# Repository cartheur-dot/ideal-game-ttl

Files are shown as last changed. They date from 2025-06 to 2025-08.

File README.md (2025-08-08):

## ideal-game-ttl

Playing around is more than half of the fun.

### References

* RAM[7400](https://github.com/emotional-toys/RAM7400)
* aeon-[ttl](https://github.com/emotional-toys/aeon-ttl)
* [SRAM](https://www.jameco.com/c/SRAM-Memory.html)

# Adding a Guess Counter to the "Guess the Hidden Number" Game

To enhance the "Guess the Hidden Number" game with a **guess counter** that tracks the number of guesses (LOAD button presses) a player makes, we’ll add logic to the existing circuit (2114 RAM, 8226, LM555, 74LS73, 74LS00, 74LS244, 74LS85, SPST switches, LEDs). The counter displays the number of guesses on LEDs and resets upon a correct guess or manual reset. The goal is to minimize additional ICs while reinforcing the reinforcement learning (RL) analogy.

## Counter Design Overview
- **Purpose**: Count LOAD button presses (guesses), display the count, and reset when the player wins (correct guess) or starts a new game.
- **Display**: Use a 4-bit binary counter (0–15 guesses) with 4 LEDs to keep the design simple, avoiding complex 7-segment display drivers.
- **Logic**:
  - Increment the counter each time the LOAD button is pressed (using the same pulse as RAM read and 74LS85 comparison).
  - Reset when the 74LS85 indicates a correct guess (`O_A=B` = 1) or via an optional manual reset switch.
- **Components**:
  - **74LS93** (4-bit binary counter) for counting.
  - 4 LEDs for binary display.
  - Reuse existing 74LS73 and 74LS00 for control signals.

## Circuit Modifications
The counter integrates with the existing circuit by using the LOAD pulse (from 74LS73) to increment and the 74LS85’s `O_A=B` output to reset. Here’s the implementation:

### 1. Counter IC: 74LS93 (4-bit Binary Counter)
- **Description**: The 74LS93 is a 4-bit ripple counter with a divide-by-2 (QA) and divide-by-8 (QB–QD) section, counting from 0000 to 1111 (0–15), sufficient for tracking guesses (typically ≤4 with binary search).
- **Pinout** (14-pin DIP):
  - **CKA (pin 14)**: Clock for QA (increments on falling edge).
  - **CKB (pin 1)**: Clock for QB–QD (connect to QA for 4-bit counting).
  - **R0(1), R0(2) (pins 2, 3)**: Reset inputs (active high, both high to reset).
  - **QA–QD (pins 12, 9, 8, 11)**: Outputs (QA = LSB, QD = MSB).
  - **VCC (pin 5)**: 5V.
  - **GND (pin 10)**: Ground.
- **Connections**:
  - **Clock**: Connect CKA (pin 14) to 74LS73 Q output (pin 5, `LOAD` pulse for `CS` and `WE`). Q’s falling edge (after `LOAD` release) triggers the counter.
  - **CKB**: Connect to QA (pin 12) for 4-bit counting.
  - **Reset**:
    - Connect R0(1) and R0(2) (pins 2, 3) to 74LS85 `O_A=B` (pin 5) via a 74LS00 NAND gate for reset on correct guess.
    - Example: Use a 74LS00 NAND gate (pins 1, 2 input, pin 3 output) with `O_A=B` and delayed LOAD pulse (via RC or second 74LS73 flip-flop) as inputs.
  - **Outputs**: Connect QA–QD (pins 12, 9, 8, 11) to 4 LEDs (L12–L15) via 550Ω bussed resistor network (1kΩ):
    - L12: QA (bit 0, LSB).
    - L13: QB (bit 1).
    - L14: QC (bit 2).
    - L15: QD (bit 3, MSB).
    - LED cathodes to GND.
  - **Decoupling**: Add 0.1 µF capacitor near pin 5 (VCC).

  _Connections_
  ```
  74LS93 (14-pin DIP)
  Pin 14 (CKA) --- 74LS73 Q (pin 5, LOAD pulse)
  Pin 1  (CKB) --- Pin 12 (QA)
  Pin 12 (QA) ---[330Ω]--- L12 (LED) --- GND
  Pin 9  (QB) ---[330Ω]--- L13 (LED) --- GND
  Pin 8  (QC) ---[330Ω]--- L14 (LED) --- GND
  Pin 11 (QD) ---[330Ω]--- L15 (LED) --- GND
  Pin 2  (R0(1)) --- 74LS00 NAND output (`O_A=B` & `LOAD`) or S15 (`VCC` w/ 10kΩ pull-down)
  Pin 3  (R0(2)) --- Same as R0(1)
  Pin 5  (VCC) --- 5V + [0.1µF capacitor] --- GND
  Pin 10 (GND) --- GND
  Pins 4, 6, 7, 13 (NC) --- Unconnected
  ```

### 2. Reset Logic
- **Automatic Reset**:
  - Reset 74LS93 when 74LS85 `O_A=B` = 1 (correct guess).
  - Use a 74LS00 NAND gate to combine `O_A=B` with LOAD pulse (74LS73 Q):
    - Inputs: `O_A=B` (74LS85 pin 5), Q (74LS73 pin 5).
    - Output: To R0(1) and R0(2) (74LS93 pins 2, 3).
    - Resets counter only on correct guess with LOAD.
- **Manual Reset** :
  - Add SPST push-button (S15) for manual reset (new game without correct guess).
  - Connect S15 between VCC and R0(1)/R0(2) with 10 kΩ pull-down resistors to GND.
  - When pressed, S15 sets R0(1) = R0(2) = 1, resetting to `0000`.

### 3. Control Integration
- **LOAD Pulse**: 74LS73 Q (pin 5) triggers:
  - 2114 RAM read (\(\overline{\text{CS}} = 0\), \(\overline{\text{WE}} = 1\)).
  - 74LS85 comparison.
  - 74LS93 increment (via CKA).
- **Timing**:
  - 1 kHz clock (LM555) ensures synchronized LOAD pulse, preventing multiple counts from button bounce.
  - 74LS93’s ~20 ns ripple delay is negligible for 1 ms clock period.
- **74LS00 Usage**:
  - Uses two NAND gates for \(\overline{\text{CS}}\) and \(\overline{\text{WE}}\) (original circuit).
  - Third gate for counter reset (`O_A=B` and `LOAD`).
  - Fourth gate for manual reset (S15).

### 4. Display
- **4 LEDs (L12–L15)**: Show guess count in binary (e.g., `0011` = 3 guesses).
- **Interpretation**: Players read binary (assume familiarity, common in digital logic contexts). Provide a reference chart (e.g., 0001 = 1, 0010 = 2).
- **Optional 7-Segment Display**:
  - A 74LS47 BCD-to-7-segment decoder and display add 1 IC and complexity. Binary LEDs minimize components.

### 5. 75LS85 Connections

```
74LS85 (16-pin DIP)
  Pin 5 (O_A>B) ---[330Ω]--- L9 (Red LED) --- GND
  Pin 7 (O_A<B) ---[330Ω]--- L10 (Yellow LED) --- GND
  Pin 6 (O_A=B) ---[330Ω]--- L11 (Green LED) --- GND
  Pin 2 (A0) ---- S9 (D0 switch)
  Pin 3 (A1) ---- S10 (D1 switch)
  Pin 4 (A2) ---- S11 (D2 switch)
  Pin 5 (A3) ---- S12 (D3 switch)
  Pin 15 (B0) --- 2114 I/O1 (pin 11)
  Pin 14 (B1) --- 2114 I/O2 (pin 12)
  Pin 13 (B2) --- 2114 I/O3 (pin 13)
  Pin 12 (B3) --- 2114 I/O4 (pin 14)
  Pin 10 (I_A>B) --- GND
  Pin 11 (I_A<B) --- GND
  Pin 9  (I_A=B) --- VCC
  Pin 16 (VCC) --- 5V + [0.1µF capacitor] --- GND
  Pin 8  (GND) --- GND
  ```

## Updated Gameplay
The game remains "Guess the Hidden Number," with the counter tracking guesses to enhance the RL analogy (minimize guesses = maximize reward).

1. **Setup**:
   - Store a 4-bit number in 2114 RAM at address `000000`, `PROGRAM`, lamps indicate data switch values; S13 = 0, `LOAD`.
   - Set address switches (S1–S6) to `000000`, R/P switch (S13) to `READ` (1), lamps indicate state from RAM.
   - Reset counter via S15 or power-on, 74LS93 outputs `0000`.

2. **Gameplay**:
   - **Step 1: Input Guess**:
     - Set data switches (S9–S12) to a 4-bit guess (e.g., `1000` = `8`).
     - Input LEDs (L1–L4) show the guess.
   - **Step 2: Submit Guess**:
     - Press LOAD (S14). 74LS73 pulse triggers:
       - 2114 RAM read (outputs stored number to 74LS85).
       - 74LS85 comparison (guess vs. stored number).
       - 74LS93 increment (e.g., `0000` → `0001`).
     - Feedback LEDs (L9–L11):
       - Red (L9): Too high `O_A>B`.
       - Yellow (L10): Too low `O_A<B`.
       - Green (L11): Correct `O_A=B`.
     - Counter LEDs (L12–L15) show count (e.g., `0001` = 1 guess).
   - **Step 3: Adjust Guess**:
     - Adjust switches based on feedback (e.g., if 8 is too low, try `1100` = `12`).
   - **Step 4: Repeat**:
     - Repeat until green LED (L11) lights.
     - On correct guess, `O_A=B` = 1 resets 74LS93 to `0000`.

3. **Winning**:
   - Win when green LED (L11) lights.
   - Note final guess count on L12–L15 before reset (e.g., `0011` = 3 guesses).
   - Optionally, enable 74LS244 to show stored number on L5–L8.

4. **New Game**:
   - Store new number or reuse same.
   - Reset counter via S15 or power cycle.

5. **RL Enhancement**:
   - **Reward**: Minimize guess count (L12–L15). Each guess = negative reward; winning = high cumulative reward.
   - **Learning**: Players refine strategy (e.g., binary search) to reduce guesses, mimicking RL policy optimization.
   - Example: Binary search takes ≤4 guesses for 0–15.

## Example Gameplay with Counter
- **Hidden Number**: 1010 (10).
- **Guess 1**: Set S9–S12 to 1000 (8), press LOAD.
  - 74LS85: 8 < 10 → Yellow LED (L10).
  - 74LS93: 0000 → 0001 (L12 on, 1 guess).
- **Guess 2**: Set 1100 (12), press LOAD.
  - 74LS85: 12 > 10 → Red LED (L9).
  - 74LS93: 0001 → 0010 (L13 on, 2 guesses).
- **Guess 3**: Set 1010 (10), press LOAD.
  - 74LS85: 10 = 10 → Green LED (L11).
  - 74LS93: 0010 → 0011 (L12, L13 on, 3 guesses), then resets to 0000.
- **Result**: Win in 3 guesses, counter shows 0011 briefly, then resets.

## Updated Bill of Materials (BoM)
| Component | Quantity | Description |
|---|---|---|
| **2114** | 1 | 1024 x 4-bit static RAM IC |
| **i8226** | 1 | 4-bit bus driver for data bus (16-pin DIP) |
| **LM555** | 1 | 555 Timer IC for 1 kHz clock |
| **74LS73** | 1 | Dual JK flip-flop for debouncing |
| **74LS00** | 1 | Quad 2-input NAND gate for control logic |
| **74LS00** | 8 | Quad 2-input NAND gate for control logic (RAM7400) |
| **74LS244** | 1 | Octal buffer/line driver for output LEDs |
| **74LS85** | 1 | 4-bit magnitude comparator for game logic |
| **74LS93** | 1 | 4-bit binary counter for guess tracking |
| **SPST Switch**  | 11 | 6 for address (S1–S6), 4 for data (S9–S12), 1 for read/write (S13) |
| **SPST Push-Button** | 2 | LOAD button (S14), Reset button (S15) |
| **LED** | 15 | 6 for address (S1–S6), 4 for input/output (L1-L4/L5–L8), 3 for feedback (L9: red, L10: yellow, L11: green), 4 for counter (L12–L15) |
| **Resistor** | 32 | 14 pull-up (4.7 kΩ), 14 pull-down (22 kΩ) for switches; 5 current-limiting resistor networks (550 Ω) for LEDs |
| **Capacitor** | 7 | 1 for 555 timer (0.1 µF), 6 for decoupling (0.1 µF near each IC) |
| **Power Supply** | 1 | 5V DC regulated supply |

**Total ICs (#pins)**: 2114 (18), LM555 (8), 74LS73 (14), 74LS00 (14), 74LS244 (20), 74LS85 (16), 74LS93(14); 7404 (14), 74LS367 (16), 8226 (16); 500-ohm-sip (14), 1k-ohm sip (18), 0.1uF (8).

## Notes
- **IC Count**: 74LS93 adds 1 IC, the simplest 4-bit counter. Cascading flip-flops (e.g., 74LS73) would require more ICs.
- **Display Simplicity**: Binary LEDs (L12–L15) minimize components vs. a 7-segment display (74LS47 + display = +1 IC, +7 resistors).
- **Reset Options**: Automatic reset (O_A=B) suffices; S15 (manual reset) is optional for testing/restarting.
- **RL Fidelity**: Counter quantifies performance (guess count = negative reward), encouraging players to optimize strategy (e.g., binary search).
- **Scalability**: For >15 guesses, cascade two 74LS93s (8-bit), but unnecessary for typical 2–4 guess range.
- **Timing**: 74LS93’s ~20 ns ripple delay is negligible for 1 kHz clock (1 ms) and human interaction.

## Conclusion
The 74LS93 counter, with 4 LEDs and minimal logic, tracks guesses, enhancing the RL analogy by quantifying performance. It integrates seamlessly, using the LOAD pulse to increment and O_A=B to reset. Players minimize guesses, mirroring RL policy optimization.

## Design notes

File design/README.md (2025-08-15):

## The design of breadboard

* Top: Two 4-bit switchers (address), one led-indicator-switches (data-input)
* Bottom: One led-indicator-2pb-switch (data-output|LOAD|RESET|R/P), one led-indicator-three (CORRECT|HIGH|LOW), one led-indicator-four (counter guess tracking)

_Print_

* 4-bit-switcher (2)
* switches-indicator-four (1) Swapped version of the original
* led-indicator-2pb-switch (1) 
* led-indicator-four (1)
* led-indicator-three (1)

### Nibble-RAM feature

[this](https://www.instructables.com/DIY-RAM-for-Your-Micro/)

### Communication

From the state of power-off to power-on, 2114 should be empty, but it is not.

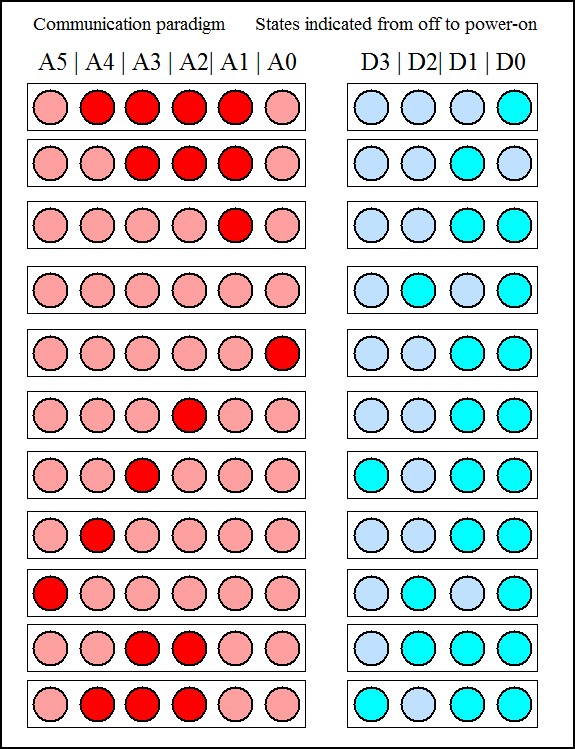
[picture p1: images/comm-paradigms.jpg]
paradigm


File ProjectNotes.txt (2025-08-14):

June 2025
Ideal game ttl

13.06.2025
    2234: Feeling gamed by the distraction of henry at the expense of dot-aeon-ttl, will shed the fiction of dotnet and return to what is real. But since unsure where to go, will start with this "Guess the number" game with the parts I have imagined. Just now finished the set of prints for the user-interface and will mount on another card, not altering what I have already created for dot.
15.06.2025
    1121: Pushing to prepare the models for printing. Will think on a "set of shared features" for ente evolving array of logic boards.
    1135: Trying an experiment to print the feature-set that belongs to the project, rather than each individually. Also generate collective stl file.
    1443: Two failed prints due to breaking-away. Maybe the 30% fill. Will print the two chunkers at default 15%.
    1722: Funk-dat, 4-bit switcher is wrongly-sized. Another print needed. Can still drill but not glue-set.
    1731: Created a two-set print of correct model.
17.06.2025
    1218: Created a project, starting-in on the UI. Need to figure a way to indicate the postion with only two LEDs.
    1230: Starting with the UI and already seeing the lameness of the AI.
    1313: Working-through the Address and Data switch-lamp, seeing buses are on the menu today.
    1413: Appended the figures to remove the second-set of components since this model is 6-bit addressing and 4-bit data.
    1418: Doping colours to ease the strain. 30,220,228 matches well.
    1533: At the 2114 diagram, still a question about the busses but need them, yes?
    1656: Generated Task03 and this is the end of this phase.
18.06.2025
    1044: Discussed RAM7400 as a way to get into memories; before that, Heiserman principle of the UI first.
    1344: Drifting toward soldering.
    1938: Soldered connections completed. COMM and 5V rails in-place. Leveraged the Vector pins with a bit of round-filing; sets well but dropped a spot of Uhoo to ensure seating over the term of the board's use.
19.06.2025
    816: Pins are set and ready to continue with the next steps.
    1148: Some minor corrections to the task diagrams and gathering the sockets. Since here, will also gather for RAM7400 since this area can be used for self-programming.
    1312: Sorted RAM7400 but needed an 8-bit port setup for the Arduino tester, which is a great interface to add larger code scenarios.
    1518: Full set of details completed for RAM7400. Ready to prototype the self-programming memory area.
    1526: Small adjustments made for clarity in documentation.
    1532: Setting-up the arduino interface.
    1640: User-interface and Arduino board ready for test on Windoze.
    1641: Sockets collected for the ideal-ttl implementation.
20.06.2025
    828: A day to continue with sockets and chips for RAM7400 dry-run.
    1038: Would be wise while at the socketing phase to understand the 2114 circuit that, as far as I know, is still not designed.
    1106: Sockets gathered. Need to add LEDs - short one but could cut a free socket for an unneeded switch.
21.06.2025
    1151: Happy Solstice! Reviewing TTL and ideal pullup values and have computed power ideal with a 4.7k resistor, using the DIP or inline types and not the silly single resistors in the Heiserman way - although in isolated form in a 16-pin DIP, this is approximately the same!
    1259: Gathered the part for the ideal aspect and listed the UI parts. Would like to begin assembly with the RAM7400 as soon as I can find a 2024 order of 2.2k bussed Bornes block resistors. Later.
    1618: Still have not found the bussers; settled on working on the UI and sized the third lamp for the success indication in the 74LS85 game.
    1811: Bussed located and set the full socket requirements for the system.
    1932: With a common ground the resistor network (bussed) is used; with a common positive the Heiserman method or isolated network is used. I suspect the following: 1. Bussed can be used on 74ls93 counter indicator, 2. Isolated on switch-LED indicator combo, 3. Bussed on pullups.
    1957: Pull parts then done for the day.
    2032: Cleaned-up the text in preparation of the build.
22.06.2025
    959: Cleared an area for digital analysis but decided against a heavy solution at the moment. Next step is to build the UI. Then, I think, the RAM7400 board to get the sense of how the logic appears.
    1003: Regarding the UI: Looking at the diagram and reading about the idea of pullup resistors, PR207 and PR208 are performing this task.
    1009: Will remove the sockets and only keep ones for the UI: 7404, 74367, 8226.
    1015: Looking at the resistor blocks (10) first as one end is connected to the 5V supply.
    1048: UI diodes: Red --> 604R; Blue --> 2.43k.
    1200: Parts are lain-out. Using the deep-cushion to mount the resistors into the 24-pin WW: SwitchRs to the left; LedRs to the right. Addresses first. Data second.
    1258: Resistors mounted, including the three RL lamps for the 7485. LEDs chosen.
    1306: Looking at the connections as the LEDs for the 7485 and the 7493 have their anodes to the respective output pins, cathode on ground.
    1401: For completeness, documented the circuit and its BoM, sans Heiserman parts.
    1403: Feeling a bit frazzled so shifting away.
    1437: Fully shifted.
23.06.2025
    2014: Still shifted. I notice that if I work through the weekend, Mondays are free.
    2021: I have contemplated the 7485 and can square the output behaviour. The only gap is from the 8226 to 2114.
    2057: Just closed the gap and updated the document.
    2110: Added the datasheet for this part.
24.06.2025
    1003: On the EVB today.
    1005: This should be a companion to aeon-ttl, as this is the prequel, the bear the product target, compact fraemwork the development environment and the output concentrated on animals-dot.
    1159: Note that this work is across three repos: This one, aeon-ttl, and animals-dot.
    1200: Finished the correction to EVB so have some free time after lunch to work on this.
    1410: Not so much free time.
    1429: 5V line to all the switch resistors, starting.
    1505: Finished the task.
    1607: Stepping into the EVB meeting.
    1846: Stepping out of the EVB meeting. Level shifters too smart for their own good.
25.06.2025
    1235: Snapping/soldering pins and WW the equivalent of U13.
    1310: Job is finished.
    1325: Thinking of the order for ideal-ttl, since the iron is here: AS0/DS0 is the extreme right (LSB).
        * Interwires between 7404 and 74367, (yellow)
        * Addr - 5V (red) and COMM (black) - internal only
        * AS resistor block to 74367, (AS0 to the inside)
        * AL resistor block to 7404, (AL0 to the inside)
        * AL to resistor block, (solder-task)
        * AS to 7404, (solder-task)
        * Data - 5V (red) and COMM (black)
        * DS resistor block to 8226, (DS0 to the inside)
        * DL resistor block to 8226, (DL0 to the inside)
        * DL to resistor block, (solder-task)
        * DS to 8226, (solder-task)
    1340: Starting-in.
    1436: All address internal WW has been completed.
    1605: Going into a meeting.
    2055: Meeting finished.
26.06.2025
    1109: Today is a day to celebrate survival. Having attended to comics, will attend to the completion of the UI.
    1142: For AS and AL, connections from each respective part to the circuit will complete.
    1150: AL0 wire mounted and ready for solder. Lunch break.
    1232: Back. Soldering iron is ready: Begin.
    1254: AL to resistor block is done.
    1319: AS to 7404 is done.
    1320: Hot today. Short break. Remember to proof in another session, just before live test.
    1424: Completed the list of tasks and DS and DL the final part.
    1511; Complete. Had to replace DS2 because of cheap connectors to plastic rather than metal. Need to keep at the Mountain - or at the minimum find a viable vista.
    1514: Looking at the data diagram and the board: What remains open are RESET, R/P, and LOAD.
    1550: Tried measuring the speaker and got a (very) rough metric. Closed the UI story as this is done.
03.08.2025
    1105: Due to machinations, this project is active.
    1310: To get warmed-up, will resume RAM7400.
05.08.2025
    1138: RAM7400 fully assembled and ready for testing. Do not want to start the validation step until construction is completed here.
    1407: Purvey things done for today.
    1434: Well, not really. Done now!
    1509: Still not really. But think so now.
    1702: Not really at all. Oxygen removed from the process.
06.08.2025
    1030: Resuming where I left-off.
    1104: Work begins.
    1246: Found an error on the 8226 chip.
    1304: Next is to delve into Task 3.
    1308: 74LS93 and 74LS85 will need to be sorted subsequent to 2114. But no LEDs to show readout! Reuse is the obvious answer, the blue datalights. Needs planning after sorting the last task- e.g., need to devise new sets of tasks
    1722: Will only work until the insertion of 2114 and work-backward to the necessary switch indicators for RAM direction - read-write.
07.08.2025
    1044: Focused to get task three completed today.
    1152: Again on the distraction. Now gathering the parts for task three.
    1202: Note to return to rodney image 0701 for test description.
    1204: First part of the task is to connect A0-A5 and D0-D3; second is to address R/P and LOAD.
    1230: Missing power line to address chips set; power and ground to 2114-18 complete.
    1311: Address and data bus connected to the 2114 socket.
08.08.2025
    1109: Next task is to sort the two switches and pushbutton...and as well to enjoy today's spirit.
    1150: Grabbed some more datasheets as the item has reappeared in the Jameco webshop.
    1225: Need to reveal some blocked parts on task02b to get the sense of how Active-Low CS and WE (2114), DIEN and CS (8216/8226) are being used. Also, do I want inverting (8226) or non-inverting (8216), given the I/O circuitry where this chip contributes is non-existant.
    1228: Well, all I will findout is that they go somewhere else. Basically: Signals are high unless pulled low, which enables these functions. Perhaps a good idea is to start testing what is onboard to get a feel of how it behaves.
    1232: Well, again, table 5.4 shows where the LOAD button is integrated, which it is currently not.
    1250: ICs need to be inserted, then testing can commence. Can do a continuity check, if concerned.
    1710: tested power from external board, rather than power supply works well for the existing waveform circuit. Plenty. Will continue with this passive method.
09.08.2025
    1104: Want to amend the task03 diagram to match the ports at-hand.
    1117: Updated the task03 image to include logic indications and not Heiserman namings.
    1119: Aded the active low circuit clarity pavel image to the repo.
10.08.2025
    1815: Despite pavels and the appearance of 1978 manifestations, want to complete the CS, WE, and LOAD connections so next session can plug-n-chug.
    1842: Had to attend to something, now starting in.
    1848: The active-low circuits have 1k pullups, as the lowest available value in documentation. Can changs since in the Heiserman fashion. Continuing.
    1923: The system is installed! :-)
11.08.2025
    1429: Fucking chumps wasting my time today. Fucking hell!
    1436: Start with a (dry) test of the lamps and switches.
    1440: LEDs functional but cannot check switches without ICs socketed. Time is here!
    1452: Chips installed.
    1455: Address lamps engaged but data not. Will look into wiring and logic analysis. Afterlife sunshine guiding me on this last preparative step.
    1538: With the HP logic clip and Elenco logic probe, seeing results and things stored in RAM. :-)
12.08.2025
    934: Another item to attend to as a priority. Current test setup is very helpful to understanding next steps.
    950: Before that: Writing and reading RAM is working but something funny in AS4 and AS6 - they seem to be partially connected together; also some crosstalk in some addresses. However, the basic concept is functional, although inverted!
    951: Nevertheless, the platform initial tests are a rousing success!
    1030: There is an issue with A5-A3; A0-A2 when looking at the 2114 work correctly, but the next set are working incorrectly. A chip-configuration problem and not the circuit. Will need to get a deeper understanding of addressing in RAM. :-) ...in this case, of course!
    1038: It also could be that CS needs a separate activity level and not tied together.
    1053: Anything stated is speculation. Need to attend to the other matter.
    1305: Found a solid source to set a new foundation of study and the pathway to validate it.
    1444: Fucking fascists are all about taking everything for themselves.
    1454: The finality of it all and the approach of wisdom in exclusion to any external deference.
13.08.2025
    1013: Paused until immediate work done. On haden.

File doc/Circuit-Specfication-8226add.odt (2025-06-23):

Your concern about the data flow into the 2114 RAM in the "Guess the Hidden Number" game circuit is valid, as the current design lacks a dedicated data bus, leading to potential contention on the bidirectional I/O pins. The proposal to add an Intel 8226 (a 4-bit bus driver) to manage data input to the 2114 is a sound approach to create a controlled data bus and isolate inputs. Below, I evaluate this idea, describe how to integrate the 8226 into the circuit with a 6-bit address bus, update the connections, and provide a revised text-based schematic and Bill of Materials (BoM), ensuring compatibility with the existing components (2114, LM555, 74LS73, 74LS00, 74LS244, 74LS85, 74LS93, switches, LEDs).

Concern: Data Flow into 2114 RAM

- Current Design Issues:
  - 2114 I/O Pins: The 2114’s I/O1–I/O4 (pins 11–14) are bidirectional and currently connected to:
    - SPST switches S7–S10 (with 10 kΩ pull-up/pull-down resistors and LEDs L1–L4).
    - 74LS85 B0–B3 (comparator inputs for the stored number).
    - 74LS244 1A1–1A4 (buffer inputs for output LEDs L5–L8).
  - Write Operation: In write mode (
    \overline{\text{CS}} = 0
    ,
    \overline{\text{WE}} = 0
    ), S7–S10 drive I/O1–I/O4, but simultaneous connections to 74LS85 and 74LS244 may cause contention, as these ICs expect stable inputs or outputs.
  - Read Operation: In read mode (
    \overline{\text{CS}} = 0
    ,
    \overline{\text{WE}} = 1
    ), the 2114 outputs data to 74LS85 and 74LS244, but switches may interfere if not isolated.
  - Problem: Without a dedicated data bus, direct switch connections risk signal integrity and contention, especially during write operations.
- Proposed Solution: Add an Intel 8226 4-bit bus driver to create a 4-bit data bus (D0–D3), isolating switch inputs during write operations and preventing contention on the 2114’s I/O pins.

Evaluating the Intel 8226 Proposal

The Intel 8226 is a 4-bit bidirectional bus driver, originally designed for microprocessor systems (e.g., Intel 8080/8085), but suitable for this TTL-based circuit to manage data flow.

- 8226 Features:
  - 4-bit Bidirectional: Four data lines with inputs (DI0–DI3) and outputs (DO0–DO3).
  - Control Pins:
    - DEN (Data Enable, pin 7): Active high, enables data transfer.
    - DIR (Direction, pin 9): Sets direction (1 = DI to DO, 0 = DO to DI).
  - TTL-Compatible: 5V operation, interfaces with 74LS series.
  - Package: 16-pin DIP.
  - Pinout:
    - DI0–DI3: Pins 3, 5, 11, 13 (inputs).
    - DO0–DO3: Pins 4, 6, 10, 12 (outputs).
    - DEN: Pin 7.
    - DIR: Pin 9.
    - VCC: Pin 16, GND: Pin 8.
    - NC: Pins 1, 2, 14, 15.
- Benefits:
  - Data Bus Creation: The 8226 isolates S7–S10 inputs from 2114 I/O1–I/O4, forming a clean 4-bit data bus for write operations.
  - Contention Prevention: Disabling the 8226 during read mode prevents switches from interfering with 2114 outputs.
  - Compatibility: Fully TTL-compatible, integrates seamlessly with existing ICs.
  - Control Simplicity: Uses S11 (read/write) and 74LS73 Q1 (LOAD pulse) for DEN and DIR control.
- Challenges:
  - Additional IC: Increases IC count from 7 to 8, slightly impacting minimalism.
  - Control Logic: Requires DEN and DIR signals, manageable with the 74LS00’s spare NAND gate.
  - Rewiring: S7–S10 disconnect from 2114 I/O1–I/O4 and connect to 8226 DI0–DI3.
  - 74LS244: Must ensure compatibility with the new data bus, as it reads 2114 outputs.
- Conclusion: The 8226 is an effective solution to establish a data bus, improving reliability and clarity of data flow with minimal complexity.

Integrating the Intel 8226

The 8226 will create a 4-bit data bus (D0–D3) where:

- Write Mode: S7–S10 drive 8226 DI0–DI3; DO0–DO3 feed 2114 I/O1–I/O4.
- Read Mode: 2114 I/O1–I/O4 output to 74LS85 B0–B3 and 74LS244 1A1–1A4; 8226 is disabled.
- Control:
  - DEN: Enabled during write (
    \overline{\text{CS}} = 0
    ,
    \overline{\text{WE}} = 0
    ) via 74LS00.
  - DIR: Tied to S11 (0 = write, DI to DO; 1 = read, DO to DI, though read direction is unused).

Modifications

1. 8226 Connections:
  - DI0–DI3: Connect to S7–S10 (with pull-up/pull-down and L1–L4).
  - DO0–DO3: Connect to 2114 I/O1–I/O4, 74LS85 B0–B3, 74LS244 1A1–1A4 (data bus).
  - DEN: Driven by 74LS00 NAND gate (74LS73 Q1 and S11).
  - DIR: Connected to S11 (write = 0, read = 1).
  - VCC, GND: 5V, ground, with 0.1 µF capacitor.
2. 2114 Rewiring:
  - Remove direct S7–S10 connections to I/O1–I/O4.
  - I/O1–I/O4 connect to 8226 DO0–DO3, 74LS85 B0–B3, 74LS244 1A1–1A4.
3. Control Logic:
  - Use 74LS00 Gate 4 to generate DEN: Inputs = 74LS73 Q1 (LOAD) and S11 (write = 0).
  - DIR = S11 (no additional logic needed).
  - Gates 1–3 unchanged (
    \overline{\text{CS}}
    ,
    \overline{\text{WE}}
    , 74LS93 reset).
4. Switches S7–S10:
  - Connect to 8226 DI0–DI3, L1–L4, retaining 10 kΩ resistors.
5. 74LS85 and 74LS244:
  - Unchanged; read 2114 I/O1–I/O4 during read mode (8226 disabled).
6. 74LS93: Unchanged; increments on 74LS73 Q1, resets on 74LS85 O_A=B.

Updated Text-Based Schematic

Below is the revised schematic with the 8226 integrated, reflecting the 6-bit address bus and new 4-bit data bus.

1. 2114 RAM (18-pin DIP)

Pin 1 (A0) --- S1 (10kΩ pull-up/pull-down)

Pin 2 (A1) --- S2

Pin 3 (A2) --- S3

Pin 4 (A3) --- S4

Pin 5 (A4) --- S5

Pin 6 (A5) --- S6

Pin 7 (A6) --- GND

Pin 8 (A7) --- GND

Pin 15 (A8) --- GND

Pin 16 (A9) --- GND

Pin 11 (I/O1) --- 8226 DO0 (pin 4) & 74LS85 B0 (pin 15) & 74LS244 1A1 (pin 2)

Pin 12 (I/O2) --- 8226 DO1 (pin 6) & 74LS85 B1 (pin 14) & 74LS244 1A2 (pin 4)

Pin 13 (I/O3) --- 8226 DO2 (pin 10) & 74LS85 B2 (pin 13) & 74LS244 1A3 (pin 6)

Pin 14 (I/O4) --- 8226 DO3 (pin 12) & 74LS85 B3 (pin 12) & 74LS244 1A4 (pin 8)

Pin 10 (\overline{WE}) --- 74LS00 pin 6

Pin 17 (\overline{CS}) --- 74LS00 pin 3

Pin 18 (VCC) --- VCC & C1 [0.1µF] --- GND

Pin 9 (GND) --- GND

2. Intel 8226 (16-pin DIP)

Pin 3 (DI0) --- S7 (10kΩ pull-up/pull-down) & R8 [330Ω] --- L1 --- GND

Pin 5 (DI1) --- S8 & R9 [330Ω] --- L2 --- GND

Pin 11 (DI2) --- S9 & R10 [330Ω] --- L3 --- GND

Pin 13 (DI3) --- S10 & R11 [330Ω] --- L4 --- GND

Pin 4 (DO0) --- 2114 I/O1 (pin 11) & 74LS85 B0 & 74LS244 1A1

Pin 6 (DO1) --- 2114 I/O2 & 74LS85 B1 & 74LS244 1A2

Pin 10 (DO2) --- 2114 I/O3 & 74LS85 B2 & 74LS244 1A3

Pin 12 (DO3) --- 2114 I/O4 & 74LS85 B3 & 74LS244 1A4

Pin 7 (DEN) --- 74LS00 pin 13 (write control)

Pin 9 (DIR) --- S11 (read/write: 0 = write, 1 = read)

Pin 16 (VCC) --- VCC & C9 [0.1µF] --- GND

Pin 8 (GND) --- GND

Pin 1, 2, 14, 15 (NC) --- Unconnected

3. LM555 (8-pin DIP)

Pin 1 (GND) --- GND

Pin 2 (TRIG) --- Pin 6 & C8 [0.1µF] --- GND

Pin 3 (OUT) --- 74LS73 CLK1 (pin 1)

Pin 4 (RESET) --- VCC

Pin 5 (CTRL) --- [0.1µF] --- GND (optional)

Pin 6 (THR) --- Pin 2 & R1 [10kΩ] --- Pin 7

Pin 7 (DISCH) --- R1 [10kΩ] --- Pin 6 & R2 [68kΩ] --- VCC

Pin 8 (VCC) --- VCC & C2 [0.1µF] --- GND

4. 74LS73 (14-pin DIP)

Pin 1 (CLK1) --- S12 (LOAD, 10kΩ pull-up/pull-down)

Pin 2 (J1) --- VCC

Pin 3 (K1) --- GND

Pin 4 (CLR1) --- VCC

Pin 5 (Q1) --- 74LS00 pin 1 (\overline{CS}), pin 4 (\overline{WE}), pin 11 (DEN), 74LS93 CKA (pin 14), 74LS00 pin 9 (reset)

Pin 6 (Q1̅) --- Unconnected

Pin 7 (GND) --- GND

Pin 8–13 (Second FF) --- Unconnected

Pin 14 (VCC) --- VCC & C3 [0.1µF] --- GND

5. 74LS00 (14-pin DIP)

Gate 1 (pins 1, 2, 3):

Pin 1 --- 74LS73 Q1 (pin 5)

Pin 2 --- VCC

Pin 3 --- 2114 \overline{CS} (pin 17)

Gate 2 (pins 4, 5, 6):

Pin 4 --- 74LS73 Q1 (pin 5)

Pin 5 --- S11 (read/write)

Pin 6 --- 2114 \overline{WE} (pin 10)

Gate 3 (pins 8, 9, 10):

Pin 8 --- 74LS85 O_A=B (pin 6)

Pin 9 --- 74LS73 Q1 (pin 5)

Pin 10 --- 74LS93 R0(1) (pin 2), R0(2) (pin 3), S13

Gate 4 (pins 11, 12, 13):

Pin 11 --- 74LS73 Q1 (pin 5)

Pin 12 --- S11 (write = 0)

Pin 13 --- 8226 DEN (pin 7)

Pin 14 (VCC) --- VCC & C4 [0.1µF] --- GND

Pin 7 (GND) --- GND

6. 74LS244 (20-pin DIP)

Pin 1 (1G̅) --- 74LS00 pin 3 (\overline{CS}) & S11 (read = 1)

Pin 2 (1A1) --- 2114 I/O1 (pin 11)

Pin 4 (1A2) --- 2114 I/O2 (pin 12)

Pin 6 (1A3) --- 2114 I/O3 (pin 13)

Pin 8 (1A4) --- 2114 I/O4 (pin 14)

Pin 18 (1Y1) --- R12 [330Ω] --- L5 --- GND

Pin 16 (1Y2) --- R13 [330Ω] --- L6 --- GND

Pin 14 (1Y3) --- R14 [330Ω] --- L7 --- GND

Pin 12 (1Y4) --- R15 [330Ω] --- L8 --- GND

Pin 19 (2G̅) --- VCC

Pin 11–17 (2A1–2A4, 2Y1–2Y4) --- Unconnected

Pin 20 (VCC) --- VCC & C5 [0.1µF] --- GND

Pin 10 (GND) --- GND

7. 74LS85 (16-pin DIP)

Pin 2 (A0) --- S7 & 8226 DI0 (pin 3)

Pin 3 (A1) --- S8 & 8226 DI1 (pin 5)

Pin 4 (A2) --- S9 & 8226 DI2 (pin 11)

Pin 5 (A3) --- S10 & 8226 DI3 (pin 13)

Pin 15 (B0) --- 2114 I/O1 (pin 11)

Pin 14 (B1) --- 2114 I/O2 (pin 12)

Pin 13 (B2) --- 2114 I/O3 (pin 13)

Pin 12 (B3) --- 2114 I/O4 (pin 14)

Pin 5 (O_A>B) --- R16 [330Ω] --- L9 (Red) --- GND

Pin 7 (O_A<B) --- R17 [330Ω] --- L10 (Yellow) --- GND

Pin 6 (O_A=B) --- R18 [330Ω] --- L11 (Green) --- GND & 74LS00 pin 8

Pin 10 (I_A>B) --- GND

Pin 11 (I_A<B) --- GND

Pin 9 (I_A=B) --- VCC

Pin 16 (VCC) --- VCC & C6 [0.1µF] --- GND

Pin 8 (GND) --- GND

8. 74LS93 (14-pin DIP)

Pin 14 (CKA) --- 74LS73 Q1 (pin 5)

Pin 1 (CKB) --- Pin 12 (QA)

Pin 12 (QA) --- R19 [330Ω] --- L12 --- GND & Pin 1 (CKB)

Pin 9 (QB) --- R20 [330Ω] --- L13 --- GND

Pin 8 (QC) --- R21 [330Ω] --- L14 --- GND

Pin 11 (QD) --- R22 [330Ω] --- L15 --- GND

Pin 2 (R0(1)) --- 74LS00 pin 10 & S13 (10kΩ pull-down)

Pin 3 (R0(2)) --- Same as R0(1)

Pin 5 (VCC) --- VCC & C7 [0.1µF] --- GND

Pin 10 (GND) --- GND

Pin 4, 6, 7, 13 (NC) --- Unconnected

9. Switches (S1–S11)

S1–S6 (A0–A5):

Each: --- 2114 pins 1–6 & R23–R28 [10kΩ pull-up] --- VCC & R29–R34 [10kΩ pull-down] --- GND

S7–S10 (D0–D3):

S7: --- 8226 DI0 (pin 3) & 74LS85 A0 (pin 2) & R8 [330Ω] --- L1 --- GND & R35 [10kΩ pull-up] --- VCC & R36 [10kΩ pull-down] --- GND

S8: --- 8226 DI1 & 74LS85 A1 & R9 [330Ω] --- L2 --- GND & R37 [10kΩ] --- VCC & R38 [10kΩ] --- GND

S9: --- 8226 DI2 & 74LS85 A2 & R10 [330Ω] --- L3 --- GND & R39 [10kΩ] --- VCC & R40 [10kΩ] --- GND

S10: --- 8226 DI3 & 74LS85 A3 & R11 [330Ω] --- L4 --- GND & R41 [10kΩ] --- VCC & R42 [10kΩ] --- GND

S11 (Read/Write):

--- 74LS00 pin 5, 74LS00 pin 12, 8226 DIR (pin 9) & R43 [10kΩ pull-up] --- VCC & R44 [10kΩ pull-down] --- GND

10. Push-Buttons (S12, S13)

S12 (LOAD): --- 74LS73 CLK1 (pin 1) & R45 [10kΩ pull-up] --- VCC & R46 [10kΩ pull-down] --- GND

S13 (Reset, optional): --- 74LS93 R0(1) (pin 2), R0(2) (pin 3) & R47 [10kΩ pull-down] --- GND

11. LEDs (L1–L15)

L1: S7 --- R8 [330Ω] --- Anode --- Cathode --- GND

L2: S8 --- R9 [330Ω] --- Anode --- Cathode --- GND

L3: S9 --- R10 [330Ω] --- Anode --- Cathode --- GND

L4: S10 --- R11 [330Ω] --- Anode --- Cathode --- GND

L5: 74LS244 1Y1 --- R12 [330Ω] --- Anode --- Cathode --- GND

L6: 74LS244 1Y2 --- R13 [330Ω] --- Anode --- Cathode --- GND

L7: 74LS244 1Y3 --- R14 [330Ω] --- Anode --- Cathode --- GND

L8: 74LS244 1Y4 --- R15 [330Ω] --- Anode --- Cathode --- GND

L9: 74LS85 O_A>B --- R16 [330Ω] --- Anode (Red) --- Cathode --- GND

L10: 74LS85 O_A<B --- R17 [330Ω] --- Anode (Yellow) --- Cathode --- GND

L11: 74LS85 O_A=B --- R18 [330Ω] --- Anode (Green) --- Cathode --- GND

L12: 74LS93 QA --- R19 [330Ω] --- Anode --- Cathode --- GND

L13: 74LS93 QB --- R20 [330Ω] --- Anode --- Cathode --- GND

L14: 74LS93 QC --- R21 [330Ω] --- Anode --- Cathode --- GND

L15: 74LS93 QD --- R22 [330Ω] --- Anode --- Cathode --- GND

12. Power Supply

VCC: 5V --- All IC VCC pins & switch pull-ups

GND: --- All IC GND pins, LED cathodes, switch pull-downs

C1–C9 [0.1µF]: Between VCC and GND near each IC (7 ICs + 8226) and LM555 timing

Updated Bill of Materials (BoM)

TSV Format for LibreOffice Writer:

Component Quantity Description

2114 1 1K x 4-bit static RAM IC (18-pin DIP)

LM555 1 555 Timer IC for 1 kHz clock (8-pin DIP)

74LS73 1 Dual JK flip-flop for debouncing (14-pin DIP)

74LS00 1 Quad 2-input NAND gate for control logic (14-pin DIP)

74LS244 1 Octal buffer/line driver for output LEDs (20-pin DIP)

74LS85 1 4-bit magnitude comparator for game logic (16-pin DIP)

74LS93 1 4-bit binary counter for guess tracking (14-pin DIP)

i8226 1 4-bit bus driver for data bus (16-pin DIP)

SPST Switch 11 6 for address (S1–S6), 4 for data (S7–S10), 1 for read/write (S11)

SPST Push-Button 2 LOAD button (S12), Reset button (S13, optional)

LED 15 4 for input (L1–L4), 4 for output (L5–L8), 3 for feedback (L9: red, L10: yellow, L11: green), 4 for counter (L12–L15)

Resistor (10 kΩ) 22 11 pull-up, 11 pull-down for switches

Resistor (330 Ω) 15 Current-limiting for LEDs

Resistor (10 kΩ) 1 LM555 timing resistor (R1)

Resistor (68 kΩ) 1 LM555 timing resistor (R2)

Capacitor (0.1 µF) 9 1 for LM555 timing (C8), 8 for decoupling (C1–C7 for ICs, C9 for 8226)

Power Supply 1 5V DC regulated supply

Data Flow with 8226

- Write Operation:
  - S11 = 0 (write), S12 pressed → 74LS73 Q1 pulses.
  - 74LS00:
    \overline{\text{CS}} = 0
    ,
    \overline{\text{WE}} = 0
    , DEN = 1 (Q1 NAND S11).
  - 8226: DIR = 0 (S11), DEN = 1, transfers S7–S10 (DI0–DI3) to 2114 I/O1–I/O4 (DO0–DO3).
  - 2114 writes data at address A0–A5 (S1–S6).
- Read Operation:
  - S11 = 1 (read), S12 pressed → Q1 pulses.
  - 74LS00:
    \overline{\text{CS}} = 0
    ,
    \overline{\text{WE}} = 1
    , DEN = 0.
  - 8226: Disabled (DEN = 0), no output to I/O1–I/O4.
  - 2114 outputs data to 74LS85 B0–B3 (comparison) and 74LS244 1A1–1A4 (L5–L8).
- Gameplay: Unchanged; player sets S7–S10, presses S12, sees L9–L11 (74LS85) and L12–L15 (74LS93).

Notes

- Improvement: The 8226 eliminates contention by isolating S7–S10 during read, ensuring clean write operations.
- IC Count: Now 8, but justified for reliability.
- Control Logic: Fully utilizes 74LS00 (all four gates).
- Timing: 8226 propagation delay (20 ns) is negligible vs. 2114 (200 ns) and 1 kHz clock (1 ms).
- Power: ~150–200 mA with additional IC.
- Alternative: A 74LS245 (octal bus transceiver) could replace the 8226, but it’s overkill (8-bit vs. 4-bit needed).

If you need a graphical schematic guide (e.g., KiCad steps), further control logic details, or a different BoM format, let me know! I can also provide troubleshooting or simulation advice.

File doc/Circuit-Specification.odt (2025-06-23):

A "Guess the Hidden Number" circuit with a 6-bit address bus, 4-bit data bus, 1 kHz clock, 2114 RAM, 8226 data bus, 74LS73, 74LS00, 74LS244, 74LS85, 74LS93, switches, push-buttons, and LEDs using accessible tools and parts that are in-stock.

Build of Materials

Component | Quantity | Description
2114 | 1 | 1K x 4-bit static RAM IC (18-pin DIP)
LM555 | 1 | 555 Timer IC for 1 kHz clock (8-pin DIP)
74LS73 | 1 | Dual JK flip-flop for debouncing (14-pin DIP)
74LS00 | 1 | Quad 2-input NAND gate for control logic (14-pin DIP)
74LS244 | 1 | Octal buffer/line driver for output LEDs (20-pin DIP)
74LS85 | 1 | 4-bit magnitude comparator for game logic (16-pin DIP)
74LS93 | 1 | 4-bit binary counter for guess tracking (14-pin DIP)
i8226 | 1 | 4-bit bus driver for data bus (16-pin DIP)
SPST Switch | 11 | 6 for address (S1–S6), 4 for data (S7–S10), 1 for read/write (S11)
SPST Push-Button | 2 | LOAD button (S12), Reset button (S13, optional)
LED | 15 | 4 for input (L1–L4), 4 for output (L5–L8), 3 for feedback (L9: red, L10: yellow, L11: green), 4 for counter (L12–L15)
Resistor (10 kΩ) | 22 | 11 pull-up, 11 pull-down for switches
Resistor (330 Ω) | 15 | Current-limiting for LEDs
Resistor (10 kΩ) | 1 | LM555 timing resistor (R1)
Resistor (68 kΩ) | 1 | LM555 timing resistor (R2)
Capacitor (0.1 µF) | 8 | 1 for LM555 timing (C8), 7 for decoupling (C1–C7, one per IC)
Power Supply | 1 | 5V DC regulated supply

Schematic Description

Here, I describe the layout and key connections, refining the text-based schematic. The circuit is organized into functional blocks for clarity.

1. Power and Ground

- VCC (5V): Connects to all IC VCC pins (2114 pin 18, LM555 pin 8, 74LS73 pin 14, 74LS00 pin 14, 74LS244 pin 20, 74LS85 pin 16, 74LS93 pin 5).
- GND: Connects to all IC GND pins (2114 pin 9, LM555 pin 1, 74LS73 pin 7, 74LS00 pin 7, 74LS244 pin 10, 74LS85 pin 8, 74LS93 pin 10), LED cathodes, and switch pull-downs.
- Decoupling Capacitors (C1–C7, 0.1 µF):
  - Place one near each IC’s VCC pin, connected between VCC and GND.
  - Example: C1 near 2114 (pin 18 to pin 9), C2 near LM555, etc.

2. Clock (LM555, 8-pin DIP)

- Purpose: 1 kHz clock for 74LS73 synchronization.
- Connections:
  LM555:
  Pin 1 (GND) --- GND
  Pin 2 (TRIG) --- Pin 6 (THR) & C8 [0.1µF] --- GND
  Pin 3 (OUT) --- 74LS73 CLK1 (pin 1)
  Pin 4 (RESET) --- VCC
  Pin 5 (CTRL) --- [0.1µF] --- GND (optional)
  Pin 6 (THR) --- Pin 2 & R1 [10kΩ] --- Pin 7
  Pin 7 (DISCH) --- R1 [10kΩ] --- Pin 6 & R2 [68kΩ] --- VCC
  Pin 8 (VCC) --- VCC & C2 [0.1µF] --- GND
- Layout: Place LM555 top-left, with R1, R2, C8 nearby. Route OUT to 74LS73.

3. Control Logic (74LS73, 74LS00)

- 74LS73 (14-pin DIP, Dual JK Flip-Flop):
  - Purpose: Debounces LOAD button (S12), generates pulse.
  - Connections:
    Pin 1 (CLK1) --- S12 (LOAD, 10kΩ pull-up to VCC, 10kΩ pull-down to GND)
    Pin 2 (J1) --- VCC
    Pin 3 (K1) --- GND
    Pin 4 (CLR1) --- VCC
    Pin 5 (Q1) --- 74LS00 pin 1 overline {CS} , pin 4 overline {WE} , 74LS93 CKA (pin 14), 74LS00 pin 9 (reset)
    Pin 6 (Q1̅) --- Unconnected
    Pin 7 (GND) --- GND
    Pin 8–13 (Second FF) --- Unconnected or CLK2 to LM555 OUT (pin 3), J2 to VCC, K2 to GND, CLR2 to VCC, Q2 to 74LS00 pin 10
    Pin 14 (VCC) --- VCC & C3 [0.1µF] --- GND
- 74LS00 (14-pin DIP, Quad NAND):
  - Purpose: Generates
    overline {CS} , overline {WE} , 74LS93 reset.
  - Connections:
    Gate 1 (pins 1, 2, 3):

Pin 1 --- 74LS73 Q1 (pin 5)

Pin 2 --- VCC

Pin 3 --- 2114 overline {CS} (pin 17)

Gate 2 (pins 4, 5, 6):

Pin 4 --- 74LS73 Q1 (pin 5)

Pin 5 --- S11 (read/write)

Pin 6 --- 2114 overline {WE} (pin 10)

Gate 3 (pins 8, 9, 10):

Pin 8 --- 74LS85 O_A=B (pin 6)

Pin 9 --- 74LS73 Q1 (pin 5)

Pin 10 --- 74LS93 R0(1) (pin 2), R0(2) (pin 3), S13

Gate 4 (pins 11, 12, 13):

Pin 11 --- 74LS73 Q1 (pin 5)

Pin 12 --- S11 (write = 0)

Pin 13 --- 8226 DEN (pin 7)

Pin 14 (VCC) --- VCC & C4 [0.1µF] --- GND

Pin 7 (GND) --- GND

    Before 8226
    Gate 1 (pins 1, 2, 3):
    Pin 1 --- 74LS73 Q1 (pin 5)
    Pin 2 --- VCC
    Pin 3 --- 2114 overline {CS} (pin 17)
    Gate 2 (pins 4, 5, 6):
    Pin 4 --- 74LS73 Q1 (pin 5)
    Pin 5 --- S11 (read/write, 10kΩ pull-up/pull-down)
    Pin 6 --- 2114 overline {WE} (pin 10)
    Gate 3 (pins 8, 9, 10):
    Pin 8 --- 74LS85 O_A=B (pin 6)
    Pin 9 --- 74LS73 Q1 (pin 5) or Q2 (pin 12)
    Pin 10 --- 74LS93 R0(1) (pin 2), R0(2) (pin 3), S13
    Gate 4 (pins 11, 12, 13):
    Pin 11 --- S13 (reset, 10kΩ pull-down) or Unconnected
    Pin 12 --- VCC or Unconnected
    Pin 13 --- 74LS93 R0(1), R0(2) or Unconnected
    Pin 14 (VCC) --- VCC & C4 [0.1µF] --- GND
    Pin 7 (GND) --- GND
- Layout: Place 8226, 74LS73, and 74LS00 centrally, near 2114. Route Q1 to multiple ICs.

4. 2114 RAM (18-pin DIP)

- Purpose: Stores 4-bit number at 6-bit address (A6–A9 grounded).
- Connections:
  Pin 1 (A0) --- S1 (10kΩ pull-up/pull-down)
  Pin 2 (A1) --- S2 (same)
  Pin 3 (A2) --- S3
  Pin 4 (A3) --- S4
  Pin 5 (A4) --- S5
  Pin 6 (A5) --- S6
  Pin 7 (A6) --- GND
  Pin 8 (A7) --- GND
  Pin 15 (A8) --- GND
  Pin 16 (A9) --- GND
  Pin 11 (I/O1) --- 8226 DO0 (pin 4) & 74LS85 B0 (pin 15) & 74LS244 1A1 (pin 2)
  Pin 12 (I/O2) --- 8226 DO1 (pin 6) & 74LS85 B1 (pin 14) & 74LS244 1A2 (pin 4)
  Pin 13 (I/O3) --- 8226 DO2 (pin 10) & 74LS85 B2 (pin 13) & 74LS244 1A3 (pin 6)
  Pin 14 (I/O4) --- 8226 DO3 (pin 12) & 74LS85 B3 (pin 12) & 74LS244 1A4 (pin 8)
  Pin 10 ( overline {WE} ) --- 74LS00 pin 6
  Pin 17 ( overline {CS} ) --- 74LS00 pin 3
  Pin 18 (VCC) --- VCC & C1 [0.1µF] --- GND
  Pin 9 (GND) --- GND
- Layout: Place centrally, with A0–A5 to switches (S1–S6), I/O1–I/O4 to switches, 74LS85, 74LS244.

5. Intel 8226 (16-pin DIP)

- Purpose: Creates data bus, isolation during read.
- Connections:
  Pin 3 (DI0) --- S7 (10kΩ pull-up/pull-down) & R8 [330Ω] --- L1 --- GND

Pin 5 (DI1) --- S8 & R9 [330Ω] --- L2 --- GND

Pin 11 (DI2) --- S9 & R10 [330Ω] --- L3 --- GND

Pin 13 (DI3) --- S10 & R11 [330Ω] --- L4 --- GND

Pin 4 (DO0) --- 2114 I/O1 (pin 11) & 74LS85 B0 & 74LS244 1A1

Pin 6 (DO1) --- 2114 I/O2 & 74LS85 B1 & 74LS244 1A2

Pin 10 (DO2) --- 2114 I/O3 & 74LS85 B2 & 74LS244 1A3

Pin 12 (DO3) --- 2114 I/O4 & 74LS85 B3 & 74LS244 1A4

Pin 7 (DEN) --- 74LS00 pin 13 (write control)

Pin 9 (DIR) --- S11 (read/write: 0 = write, 1 = read)

Pin 16 (VCC) --- VCC & C9 [0.1µF] --- GND

Pin 8 (GND) --- GND

Pin 1, 2, 14, 15 (NC) --- Unconnected

6. 74LS244 (20-pin DIP, Octal Buffer)

- Purpose: Buffers RAM output for L5–L8 (optional).
- Connections:
  Pin 1 (1G̅) --- 74LS00 pin 3 ( overline {CS} ) & S11 (read = 1)
  Pin 2 (1A1) --- 2114 I/O1 (pin 11)
  Pin 4 (1A2) --- 2114 I/O2 (pin 12)
  Pin 6 (1A3) --- 2114 I/O3 (pin 13)
  Pin 8 (1A4) --- 2114 I/O4 (pin 14)
  Pin 18 (1Y1) --- R12 [330Ω] --- L5 --- GND
  Pin 16 (1Y2) --- R13 [330Ω] --- L6 --- GND
  Pin 14 (1Y3) --- R14 [330Ω] --- L7 --- GND
  Pin 12 (1Y4) --- R15 [330Ω] --- L8 --- GND
  Pin 19 (2G̅) --- VCC
  Pin 11–17 (2A1–2A4, 2Y1–2Y4) --- Unconnected
  Pin 20 (VCC) --- VCC & C5 [0.1µF] --- GND
  Pin 10 (GND) --- GND
- Layout: Place near 2114, with outputs to L5–L8 (bottom-right).

7. 74LS85 (16-pin DIP, Comparator)

- Purpose: Compares guess vs. RAM data, drives L9–L11.
- Connections:
  Pin 2 (A0) --- S7 & 2114 I/O1
  Pin 3 (A1) --- S8 & 2114 I/O2
  Pin 4 (A2) --- S9 & 2114 I/O3
  Pin 5 (A3) --- S10 & 2114 I/O4
  Pin 15 (B0) --- 2114 I/O1 (pin 11)
  Pin 14 (B1) --- 2114 I/O2 (pin 12)
  Pin 13 (B2) --- 2114 I/O3 (pin 13)
  Pin 12 (B3) --- 2114 I/O4 (pin 14)
  Pin 5 (O_A>B) --- R16 [330Ω] --- L9 (Red) --- GND
  Pin 7 (O_A<B) --- R17 [330Ω] --- L10 (Yellow) --- GND
  Pin 6 (O_A=B) --- R18 [330Ω] --- L11 (Green) --- GND & 74LS00 pin 8
  Pin 10 (I_A>B) --- GND
  Pin 11 (I_A<B) --- GND
  Pin 9 (I_A=B) --- VCC
  Pin 16 (VCC) --- VCC & C6 [0.1µF] --- GND
  Pin 8 (GND) --- GND
- Layout: Place near 2114, with outputs to L9–L11 (right).

8. 74LS93 (14-pin DIP, Counter)

- Purpose: Counts guesses, drives L12–L15.
- Connections:
  Pin 14 (CKA) --- 74LS73 Q1 (pin 5)
  Pin 1 (CKB) --- Pin 12 (QA)
  Pin 12 (QA) --- R19 [330Ω] --- L12 --- GND & Pin 1 (CKB)
  Pin 9 (QB) --- R20 [330Ω] --- L13 --- GND
  Pin 8 (QC) --- R21 [330Ω] --- L14 --- GND
  Pin 11 (QD) --- R22 [330Ω] --- L15 --- GND
  Pin 2 (R0(1)) --- 74LS00 pin 10 & S13 (10kΩ pull-down)
  Pin 3 (R0(2)) --- Same as R0(1)
  Pin 5 (VCC) --- VCC & C7 [0.1µF] --- GND
  Pin 10 (GND) --- GND
  Pin 4, 6, 7, 13 (NC) --- Unconnected
- Layout: Place near 74LS85, with outputs to L12–L15 (bottom).

9. Switches (S1–S11)

- Connections:
  S1–S6 (A0–A5):
  Each: --- 2114 pins 1–6 & R23–R28 [10kΩ pull-up] --- VCC & R29–R34 [10kΩ pull-down] --- GND
  S7–S10 (D0–D3):
  S7: --- 2114 I/O1 & 74LS85 A0 & 74LS244 1A1 & R8 [330Ω] --- L1 --- GND & R35 [10kΩ pull-up] --- VCC & R36 [10kΩ pull-down] --- GND
  S8: --- 2114 I/O2 & 74LS85 A1 & 74LS244 1A2 & R9 [330Ω] --- L2 --- GND & R37 [10kΩ] --- VCC & R38 [10kΩ] --- GND
  S9: --- 2114 I/O3 & 74LS85 A2 & 74LS244 1A3 & R10 [330Ω] --- L3 --- GND & R39 [10kΩ] --- VCC & R40 [10kΩ] --- GND
  S10: --- 2114 I/O4 & 74LS85 A3 & 74LS244 1A4 & R11 [330Ω] --- L4 --- GND & R41 [10kΩ] --- VCC & R42 [10kΩ] --- GND
  S11 (Read/Write):
  --- 74LS00 pin 5 & R43 [10kΩ pull-up] --- VCC & R44 [10kΩ pull-down] --- GND

10. Push-Buttons (S12, S13)

- Connections:
  S12 (LOAD): --- 74LS73 CLK1 (pin 1) & R45 [10kΩ pull-up] --- VCC & R46 [10kΩ pull-down] --- GND
  S13 (Reset): --- 74LS93 R0(1) (pin 2), R0(2) (pin 3) & R47 [10kΩ pull-down] --- GND

11. LEDs (L1–L15)

- Connections:
  L1: S7 --- R8 [330Ω] --- Anode --- Cathode --- GND
  L2: S8 --- R9 [330Ω] --- Anode --- Cathode --- GND
  L3: S9 --- R10 [330Ω] --- Anode --- Cathode --- GND
  L4: S10 --- R11 [330Ω] --- Anode --- Cathode --- GND
  L5: 74LS244 1Y1 --- R12 [330Ω] --- Anode --- Cathode --- GND
  L6: 74LS244 1Y2 --- R13 [330Ω] --- Anode --- Cathode --- GND
  L7: 74LS244 1Y3 --- R14 [330Ω] --- Anode --- Cathode --- GND
  L8: 74LS244 1Y4 --- R15 [330Ω] --- Anode --- Cathode --- GND
  L9: 74LS85 O_A>B --- R16 [330Ω] --- Anode (Red) --- Cathode --- GND
  L10: 74LS85 O_A<B --- R17 [330Ω] --- Anode (Yellow) --- Cathode --- GND
  L11: 74LS85 O_A=B --- R18 [330Ω] --- Anode (Green) --- Cathode --- GND
  L12: 74LS93 QA --- R19 [330Ω] --- Anode --- Cathode --- GND
  L13: 74LS93 QB --- R20 [330Ω] --- Anode --- Cathode --- GND
  L14: 74LS93 QC --- R21 [330Ω] --- Anode --- Cathode --- GND
  L15: 74LS93 QD --- R22 [330Ω] --- Anode --- Cathode --- GND

12. Power Supply

- Connections:
  VCC: 5V --- All IC VCC pins & switch pull-ups
  GND: --- All IC GND pins, LED cathodes, switch pull-downs
  C1–C7 [0.1µF]: Between VCC and GND near each IC

Data Flow with 8226

- Write Operation:
  - S11 = 0 (write), S12 pressed → 74LS73 Q1 pulses.
  - 74LS00:
    overline {CS} = 0, overline {WE} = 0, DEN = 1 (Q1 NAND S11).
  - 8226: DIR = 0 (S11), DEN = 1, transfers S7–S10 (DI0–DI3) to 2114 I/O1–I/O4 (DO0–DO3).
  - 2114 writes data at address A0–A5 (S1–S6).
- Read Operation:
  - S11 = 1 (read), S12 pressed → Q1 pulses.
  - 74LS00:
    overline {CS} = 0, overline {WE} = 1, DEN = 0.
  - 8226: Disabled (DEN = 0), no output to I/O1–I/O4.
  - 2114 outputs data to 74LS85 B0–B3 (comparison) and 74LS244 1A1–1A4 (L5–L8).
- Gameplay: Unchanged; player sets S7–S10, presses S12, sees L9–L11 (74LS85) and L12–L15 (74LS93).

Notes

- Improvement: The 8226 eliminates contention by isolating S7–S10 during read, ensuring clean write operations.
- IC Count: Now 8, but justified for reliability.
- Control Logic: Fully utilizes 74LS00 (all four gates).
- Timing: 8226 propagation delay (20 ns) is negligible vs. 2114 (200 ns) and 1 kHz clock (1 ms).
- Power: ~150–200 mA with additional IC.
- Alternative: A 74LS245 (octal bus transceiver) could replace the 8226, but it’s overkill (8-bit vs. 4-bit needed).

Visual Layout for Graphical Schematic

- Top-Left: LM555 (clock) with R1, R2, C8.
- Top-Center: 74LS73, 74LS00, S12 (LOAD), S13 (reset), S11 (read/write).
- Center: 2114 RAM, with S1–S6 (address), S7–S10 (data), L1–L4 (input LEDs).
- Right: 74LS85, with L9–L11 (feedback LEDs).
- Bottom-Right: 74LS244, with L5–L8 (output LEDs).
- Bottom: 74LS93, with L12–L15 (counter LEDs).
- Buses:
  - 6-bit address (A0–A5): S1–S6 to 2114.
  - 4-bit data (D0–D3): S7–S10 to 2114, 74LS85, 74LS244, L1–L4.
- Power: VCC, GND rails across top/bottom, capacitors near ICs.

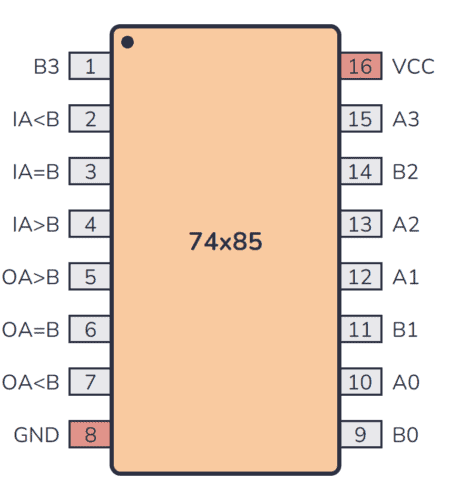
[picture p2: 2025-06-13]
images/7485-pinout.png

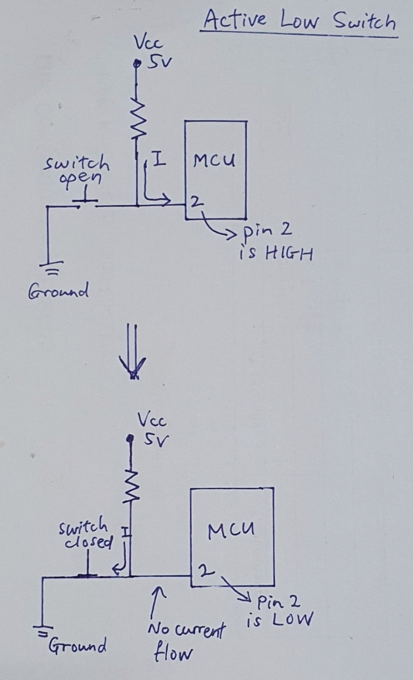
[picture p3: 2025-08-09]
images/active-low-arrangement.jpg

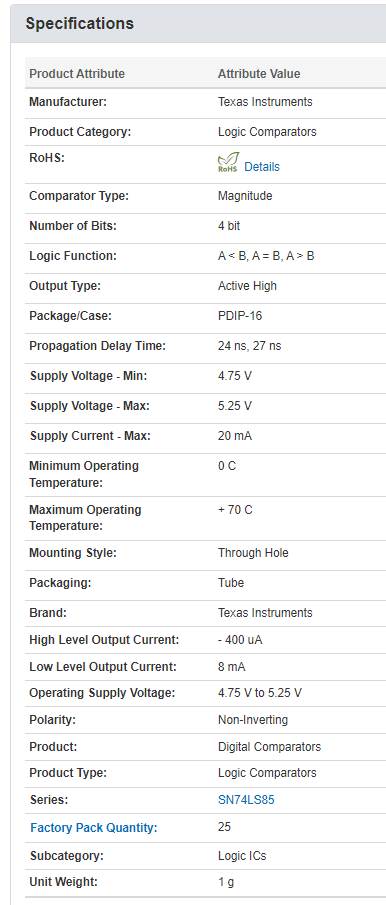
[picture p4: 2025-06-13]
images/74LS85N-2.png

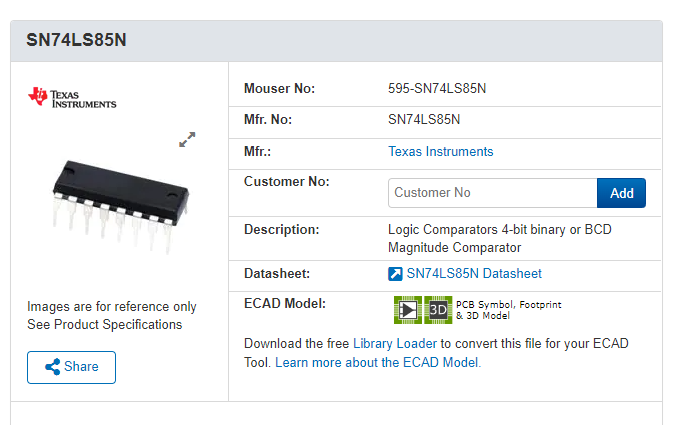
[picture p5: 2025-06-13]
images/74LS85N-1.png

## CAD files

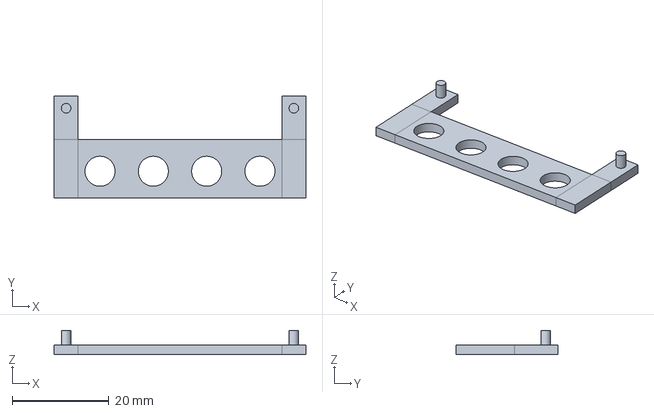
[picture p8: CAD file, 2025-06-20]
design/led-indicator-four.FCStd
52.0 x 21.0 x 5.00 mm

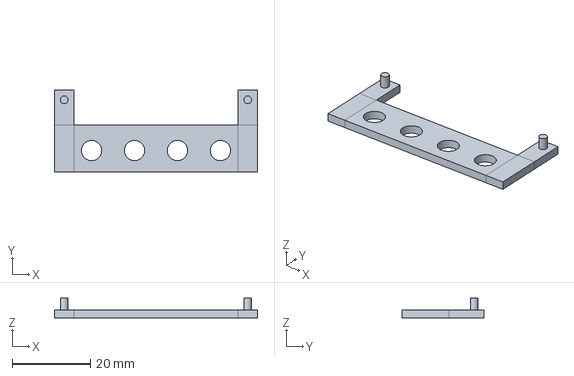
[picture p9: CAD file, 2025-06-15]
design/4-bit-switcher.FCStd
52.0 x 21.0 x 5.00 mm

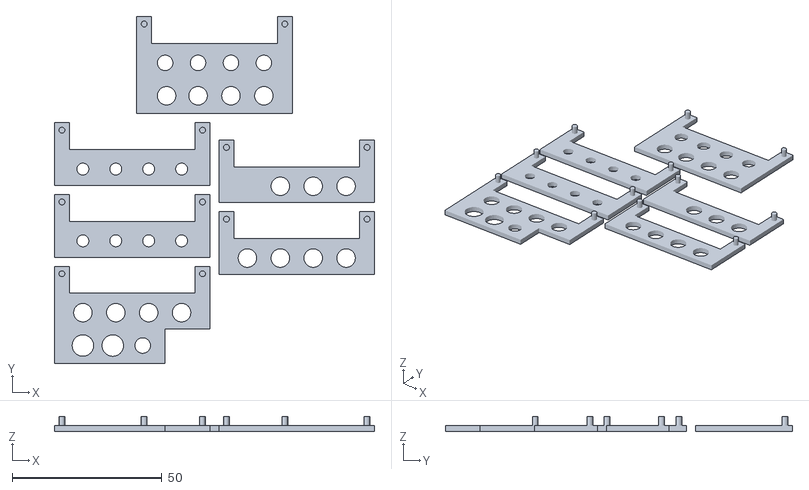
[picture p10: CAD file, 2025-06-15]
design/design-feature-set.stl
107.0 x 116.0 x 5.00

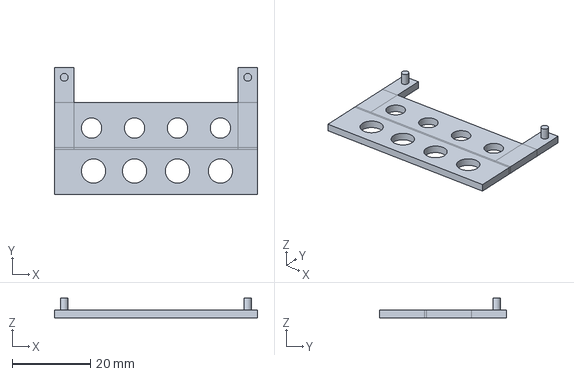
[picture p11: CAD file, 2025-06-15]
design/switches-indicator-four.FCStd
52.0 x 32.5 x 5.00 mm

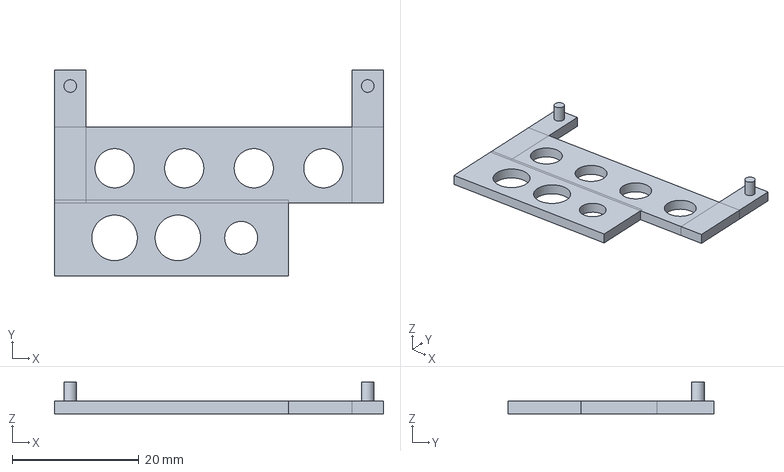
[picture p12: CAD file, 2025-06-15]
design/led-indicator-2pb-switch.FCStd
52.0 x 32.5 x 5.00 mm

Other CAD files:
design/led-indicator-three.FCStd
design/4-bit-switcher.stl
design/led-indicator-2pb-switch.stl
design/led-indicator-four.stl
design/led-indicator-three.stl
design/switches-indicator-four.stl

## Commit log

2025-06-13 Initial version
    [led-indicator-switches.FCStd, led-indicator-switches.stl]
2025-06-15 Add design
    [4-bit-switcher.FCStd, 4-bit-switcher.stl, led-indicator-2pb-switch.FCStd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]
2025-06-15 Add feature-set model
    [design-feature-set.stl]
2025-06-15 Set proper hole size
    [4-bit-switcher.FCStd, 4-bit-switcher.stl]
2025-06-17 Resistors onhand
2025-06-20 Add number of pins to BoM
2025-06-20 Add copyright information
    [led-indicator-four.FCStd]
2025-06-21 Include UI parts BoM
2025-08-09 Add active low circuit diagram
